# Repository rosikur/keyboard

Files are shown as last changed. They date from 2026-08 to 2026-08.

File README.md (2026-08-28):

# keyboard

I dont know what to call it so lets call it "keeb" because thats the name  of  the guide

This was my first keyboard , apart from my macropad ,the keyboard took 3 times , more on that on my Journal

## Features
- Us keyboard
- Del key with fn + Backspace
- 75 %
- Made with lots of hate and Caffeine
- Rotary Encoder
## How to assemble
First you go to jlcpcb and uplood the gerber files, i recommend black pcb colors
Then you go to Aliexpress and order all the parts from the BOM

In the meantime while it ships you start printing the Case,if your Printer is too small , half it or you can order it off print legion

Once everything is ready , you grab some solder and an iron , i recommend leaded solder makes it easier,firstly take your pi pico and add the  male pins,then put it trough and solder everything and snap off its legs outside

Then take your diodes,and turn the board around ,make sure the diodes are pointing  down in orientation and solder them,snap off its legs 

Then take your switchs,turn the board around and pit them all in and solder them one by one 

Last but not least ,add the rotary encoder and solder it

Also add the Stabalizers , watch a tiktok to put them togehter

put the ready board in the case add heated inserts and screw it together

add the key caps and youre done with assembly:D

## How to Software 
Set the Pi Pico to its Bootloader and connect it to your pc  take the uf2 zip and unzip , 

move the file to the pi labelled usb driver

thats it have fun! 

## Picture Gallary
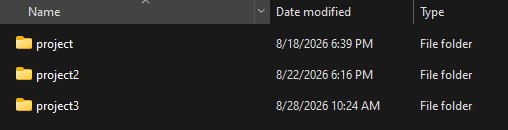
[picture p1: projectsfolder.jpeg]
3 Folders

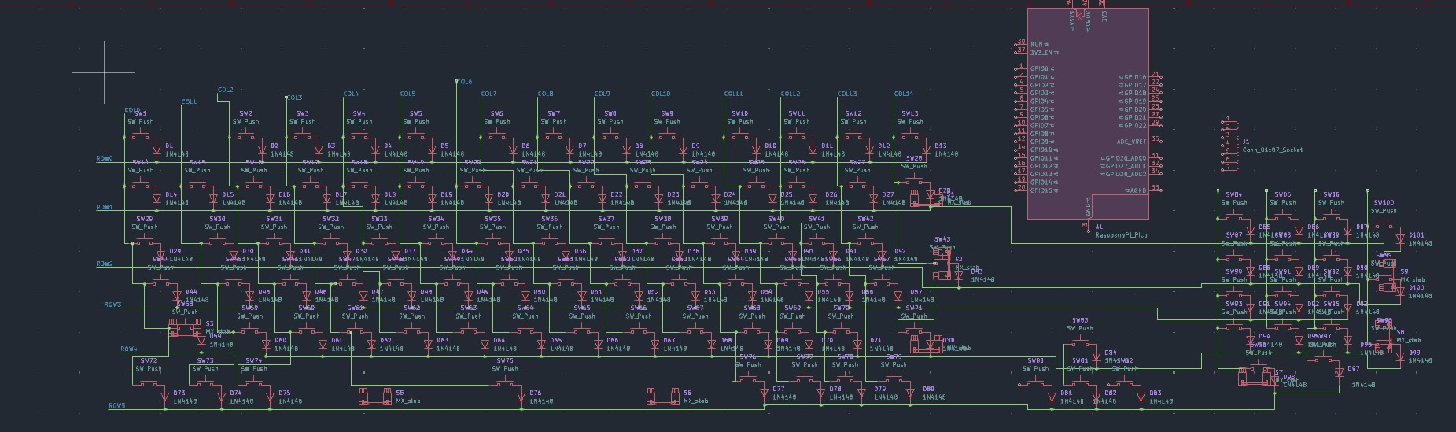
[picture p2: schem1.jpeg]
Schematic in the first folder

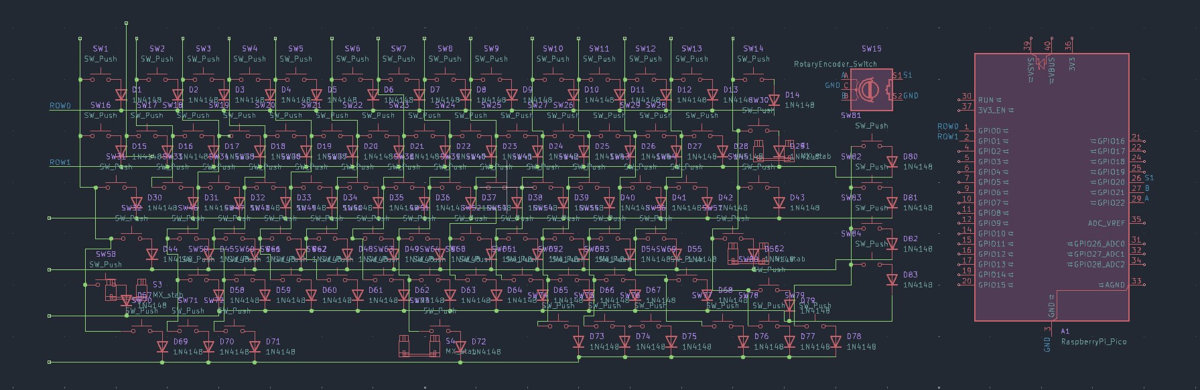
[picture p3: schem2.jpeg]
Schematic in the second folder

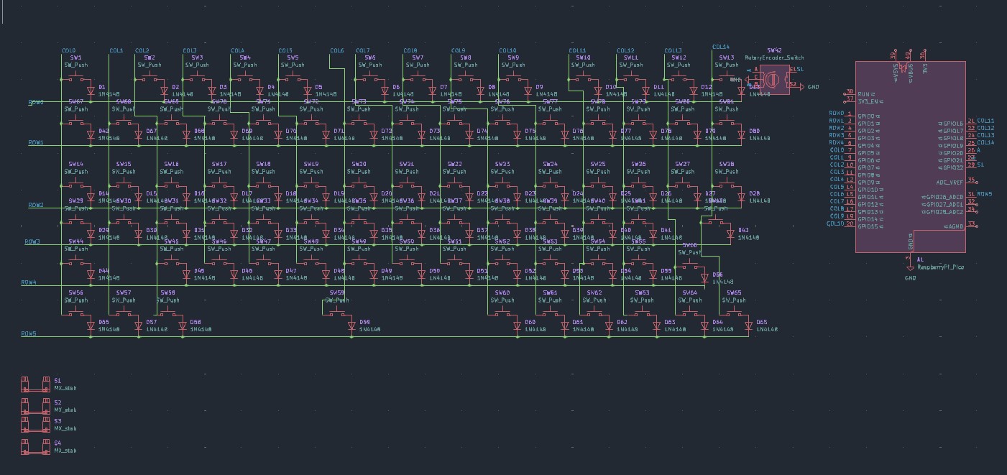
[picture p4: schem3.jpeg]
Schematic in the third folder

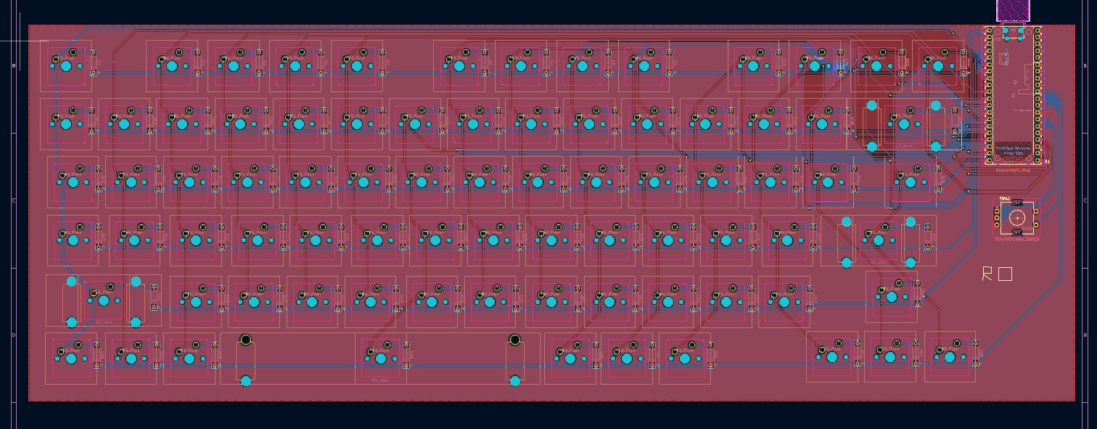
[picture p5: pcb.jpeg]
pcb

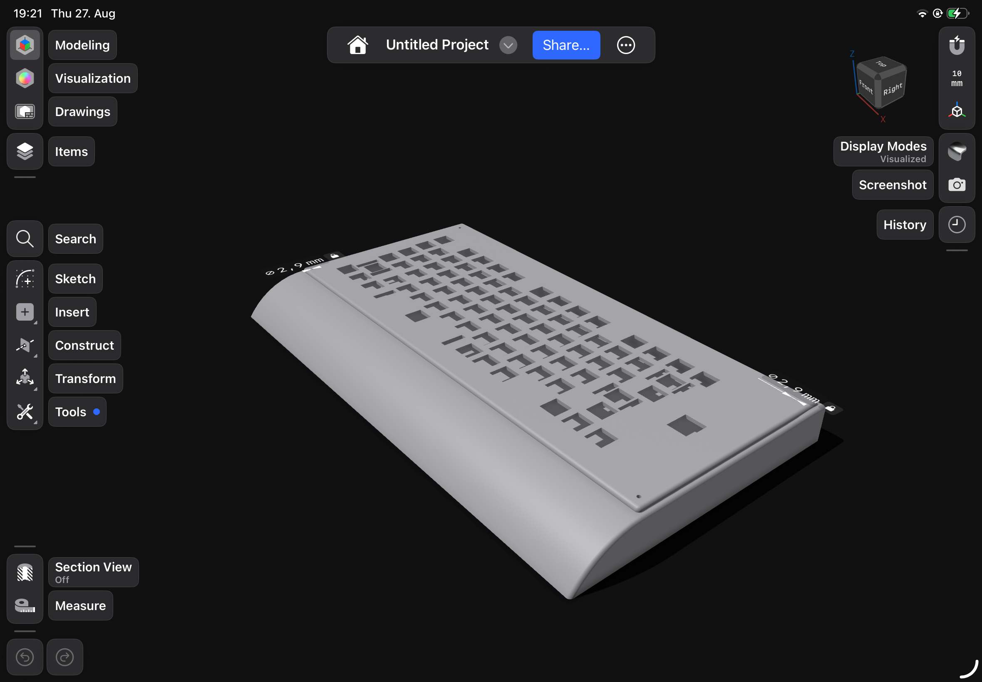
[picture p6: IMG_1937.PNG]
Cad software showing a keyboard


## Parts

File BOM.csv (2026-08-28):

Item | QNT | Price | Link | details
Switches | 162 | 13.39/45 * 4 = 53.56EUR = 62.48USD | https://a.aliexpress.com/_EJTCEpM | AKKO v3 pro cream blue
Keycaps | 2 Sets | 16.99EUR * 2 = 33.98EUR = 39.64USD | https://a.aliexpress.com/_Eyr32DU | cuul mc keycaps
Diodes | 160 | 1.39*2 + Duties = 5.78 | https://a.aliexpress.com/_EGyImLY
Rotary Encoder | 2 | 6.49+ Duties 3Eur = 9.49 Eur | https://a.aliexpress.com/_EjwhFqK
Orpheus Pico | 2 | 3.05 *2 + Duties = 9.10 | https://a.aliexpress.com/_ExrMmQe | in reality its a knockoff pi pico
PCB |  | 37.39
Cable |  | 6.49+ duties =9.49 | https://a.aliexpress.com/_EwkdJdC
MX Stab |  | 6.19+ Duties =9.19 | https://a.aliexpress.com/_EHf4OAA
 |  | welps that got out of hand
 |  | Total 167.98 EUR = 196.01

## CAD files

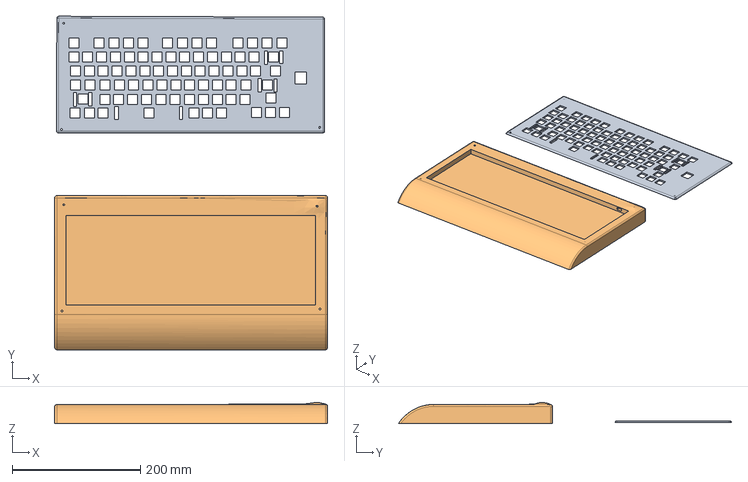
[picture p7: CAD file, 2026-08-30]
Case.step
425.0 x 519.3 x 33.4 mm

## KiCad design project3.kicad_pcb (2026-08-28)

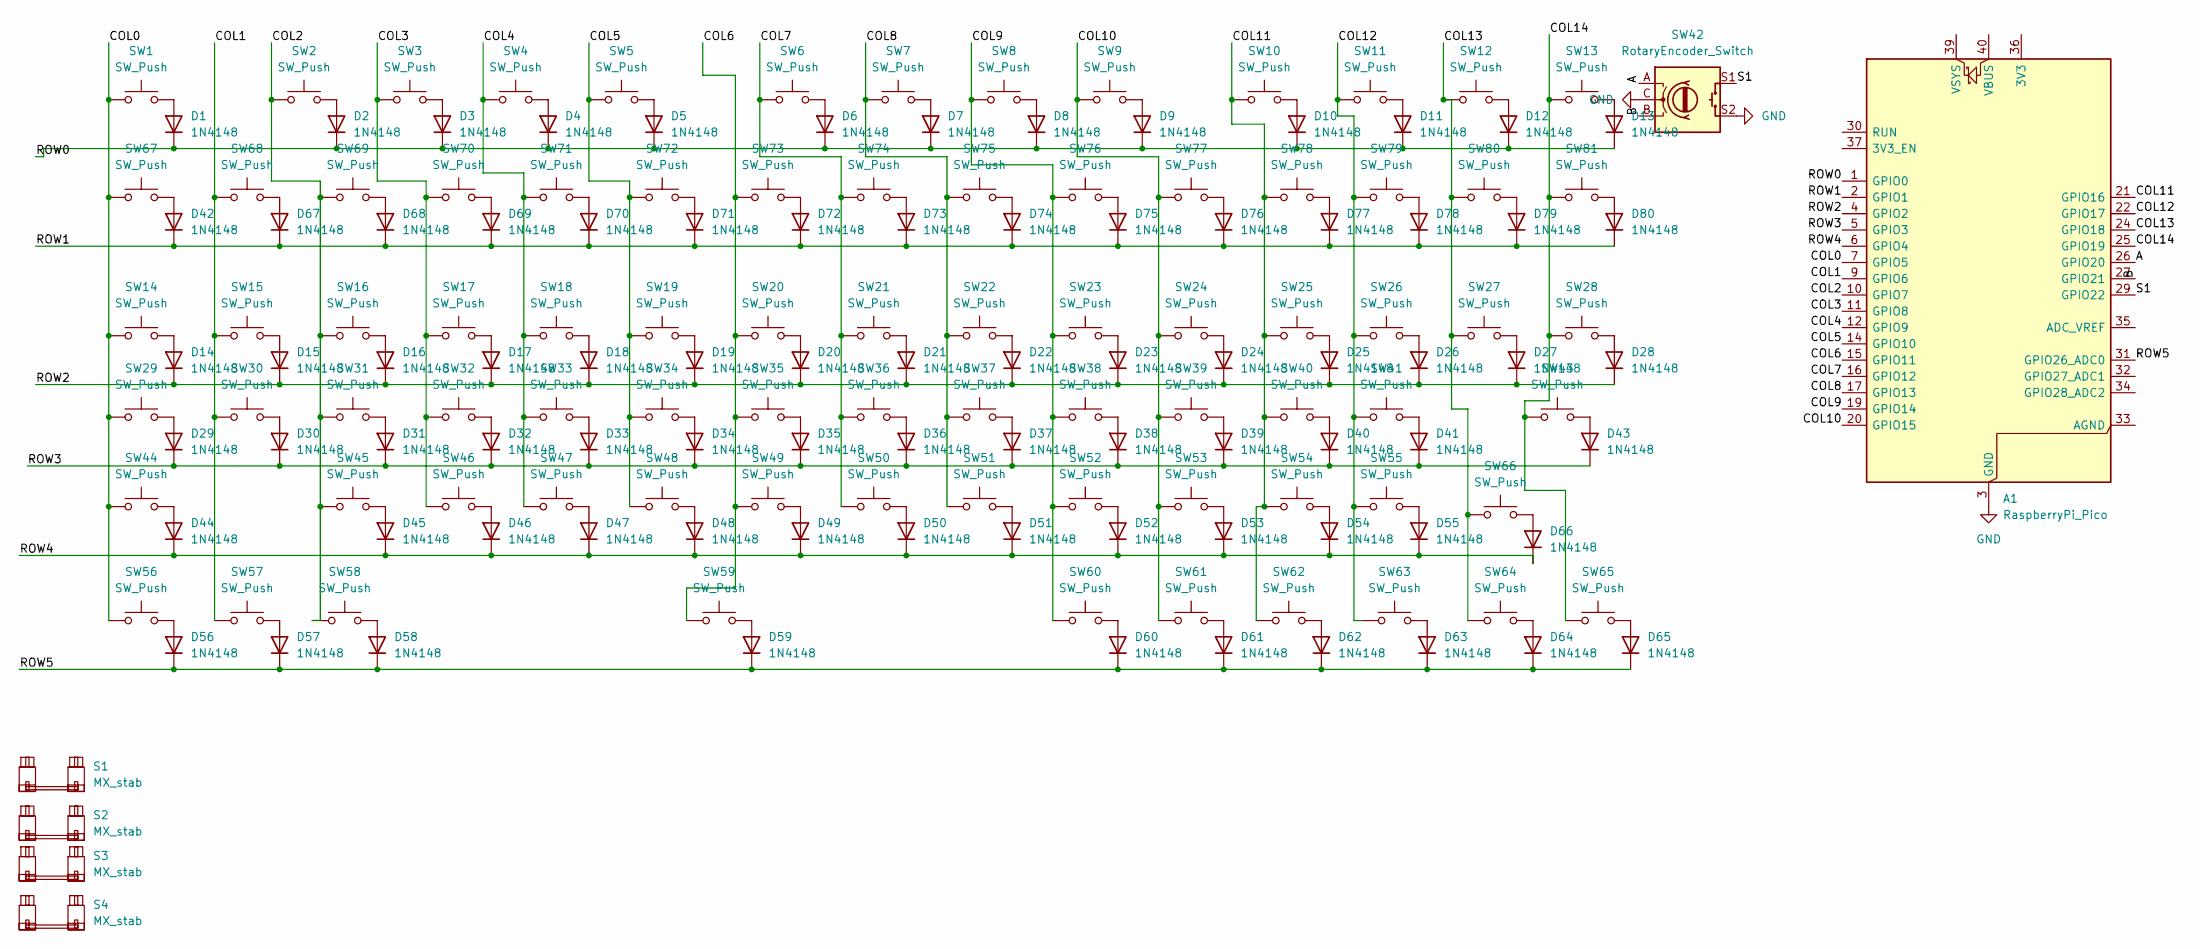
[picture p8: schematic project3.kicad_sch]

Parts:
A1: RaspberryPi_Pico; RaspberryPi_Pico_Common_Unspecified
D1, D2, D3, D4, D5, D6, D7, D8, D9, D10, D11, D12, D13, D14, D15, D16, D17, D18, D19, D20, D21, D22, D23, D24, D25, D26, D27, D28, D29, D30, D31, D32, D33, D34, D35, D36, D37, D38, D39, D40, D41, D42, D43, D44, D45, D46, D47, D48, D49, D50, D51, D52, D53, D54, D55, D56, D57, D58, D59, D60, D61, D62, D63, D64, D65, D66, D67, D68, D69, D70, D71, D72, D73, D74, D75, D76, D77, D78, D79, D80: 1N4148; D_DO-35_SOD27_P7.62mm_Horizontal
S1: MX_stab; STAB_MX_P_6.25u
S2, S3, S4: MX_stab; STAB_MX_2.25u
SW1, SW2, SW3, SW4, SW5, SW6, SW7, SW8, SW9, SW10, SW11, SW12, SW13, SW14, SW15, SW16, SW17, SW18, SW19, SW20, SW21, SW22, SW23, SW24, SW25, SW26, SW27, SW28, SW29, SW30, SW31, SW32, SW33, SW34, SW35, SW36, SW37, SW38, SW39, SW40, SW41, SW43, SW44, SW45, SW46, SW47, SW48, SW49, SW50, SW51, SW52, SW53, SW54, SW55, SW56, SW57, SW58, SW59, SW60, SW61, SW62, SW63, SW64, SW65, SW66, SW67, SW68, SW69, SW70, SW71, SW72, SW73, SW74, SW75, SW76, SW77, SW78, SW79, SW80, SW81: SW_Push; SW_MX_1u
SW42: RotaryEncoder_Switch; RotaryEncoder_Alps_EC11E-Switch_Vertical_H20mm

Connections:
/A: A1.26 (GPIO20), SW42.A
/B: A1.27 (GPIO21), SW42.B
/COL0: A1.7 (GPIO5), SW1.1, SW14.1, SW29.1, SW44.1, SW56.1, SW67.1
/COL1: A1.9 (GPIO6), SW15.1, SW30.1, SW57.1, SW68.1
/COL2: A1.10 (GPIO7), SW2.1, SW16.1, SW31.1, SW45.1, SW58.1, SW69.1
/COL4: A1.12 (GPIO9), SW4.1, SW18.1, SW33.1, SW47.1, SW71.1
/COL5: A1.14 (GPIO10), SW5.1, SW19.1, SW34.1, SW48.1, SW72.1
/COL6: A1.15 (GPIO11), SW20.1, SW35.1, SW49.1, SW59.1, SW73.1
/COL7: A1.16 (GPIO12), SW6.1, SW21.1, SW36.1, SW50.1, SW74.1
/COL8: A1.17 (GPIO13), SW7.1, SW22.1, SW37.1, SW51.1, SW75.1
/COL9: A1.19 (GPIO14), SW8.1, SW23.1, SW38.1, SW52.1, SW60.1, SW76.1
/COL10: A1.20 (GPIO15), SW9.1, SW24.1, SW39.1, SW53.1, SW61.1, SW77.1
/COL11: A1.21 (GPIO16), SW10.1, SW25.1, SW40.1, SW54.1, SW62.1, SW78.1
/COL12: A1.22 (GPIO17), SW11.1, SW26.1, SW41.1, SW55.1, SW63.1, SW79.1
/COL13: A1.24 (GPIO18), SW12.1, SW27.1, SW64.1, SW66.1, SW80.1
/COL14: A1.25 (GPIO19), SW13.1, SW28.1, SW43.1, SW65.1, SW81.1
/ROW0: A1.1 (GPIO0), D1.1 (K), D2.1 (K), D3.1 (K), D4.1 (K), D5.1 (K), D6.1 (K), D7.1 (K), D8.1 (K), D9.1 (K), D10.1 (K), D11.1 (K), D12.1 (K), D13.1 (K)
/ROW1: A1.2 (GPIO1), D42.1 (K), D67.1 (K), D68.1 (K), D69.1 (K), D70.1 (K), D71.1 (K), D72.1 (K), D73.1 (K), D74.1 (K), D75.1 (K), D76.1 (K), D77.1 (K), D78.1 (K), D79.1 (K), D80.1 (K)
/ROW2: A1.4 (GPIO2), D14.1 (K), D15.1 (K), D16.1 (K), D17.1 (K), D18.1 (K), D19.1 (K), D20.1 (K), D21.1 (K), D22.1 (K), D23.1 (K), D24.1 (K), D25.1 (K), D26.1 (K), D27.1 (K), D28.1 (K)
/ROW3: A1.5 (GPIO3), D29.1 (K), D30.1 (K), D31.1 (K), D32.1 (K), D33.1 (K), D34.1 (K), D35.1 (K), D36.1 (K), D37.1 (K), D38.1 (K), D39.1 (K), D40.1 (K), D41.1 (K), D43.1 (K)
/ROW4: A1.6 (GPIO4), D44.1 (K), D45.1 (K), D46.1 (K), D47.1 (K), D48.1 (K), D49.1 (K), D50.1 (K), D51.1 (K), D52.1 (K), D53.1 (K), D54.1 (K), D55.1 (K), D66.1 (K)
/ROW5: A1.31 (GPIO26_ADC0), D56.1 (K), D57.1 (K), D58.1 (K), D59.1 (K), D60.1 (K), D61.1 (K), D62.1 (K), D63.1 (K), D64.1 (K), D65.1 (K)
/S1: A1.29 (GPIO22), SW42.S1
GND: A1.3 (GND), A1.8 (GND), A1.13 (GND), A1.18 (GND), A1.23 (GND), A1.28 (GND), A1.38 (GND), SW42.C, SW42.S2
unnamed: D1.2 (A), SW1.2
unnamed: D2.2 (A), SW2.2
unnamed: D3.2 (A), SW3.2
unnamed: D4.2 (A), SW4.2
unnamed: D5.2 (A), SW5.2
unnamed: D6.2 (A), SW6.2
unnamed: D7.2 (A), SW7.2
unnamed: D8.2 (A), SW8.2
unnamed: D9.2 (A), SW9.2
unnamed: D10.2 (A), SW10.2
unnamed: D11.2 (A), SW11.2
unnamed: D12.2 (A), SW12.2
unnamed: D13.2 (A), SW13.2
unnamed: D14.2 (A), SW14.2
unnamed: D15.2 (A), SW15.2
unnamed: D16.2 (A), SW16.2
unnamed: D17.2 (A), SW17.2
unnamed: D18.2 (A), SW18.2
unnamed: D19.2 (A), SW19.2
unnamed: D20.2 (A), SW20.2
unnamed: D21.2 (A), SW21.2
unnamed: D22.2 (A), SW22.2
unnamed: D23.2 (A), SW23.2
unnamed: D24.2 (A), SW24.2
unnamed: D25.2 (A), SW25.2
unnamed: D26.2 (A), SW26.2
unnamed: D27.2 (A), SW27.2
unnamed: D28.2 (A), SW28.2
unnamed: D29.2 (A), SW29.2
unnamed: D30.2 (A), SW30.2
unnamed: D31.2 (A), SW31.2
unnamed: D32.2 (A), SW32.2
unnamed: D33.2 (A), SW33.2
unnamed: D34.2 (A), SW34.2
unnamed: D35.2 (A), SW35.2
unnamed: D36.2 (A), SW36.2
unnamed: D37.2 (A), SW37.2
unnamed: D38.2 (A), SW38.2
unnamed: D39.2 (A), SW39.2
unnamed: D40.2 (A), SW40.2
unnamed: D41.2 (A), SW41.2
unnamed: D42.2 (A), SW67.2
unnamed: D43.2 (A), SW43.2
unnamed: D44.2 (A), SW44.2
unnamed: D45.2 (A), SW45.2
unnamed: D46.2 (A), SW46.2
unnamed: D47.2 (A), SW47.2
unnamed: D48.2 (A), SW48.2
unnamed: D49.2 (A), SW49.2
unnamed: D50.2 (A), SW50.2
unnamed: D51.2 (A), SW51.2
unnamed: D52.2 (A), SW52.2
unnamed: D53.2 (A), SW53.2
unnamed: D54.2 (A), SW54.2
unnamed: D55.2 (A), SW55.2
unnamed: D56.2 (A), SW56.2
unnamed: D57.2 (A), SW57.2
unnamed: D58.2 (A), SW58.2
unnamed: D59.2 (A), SW59.2
unnamed: D60.2 (A), SW60.2
unnamed: D61.2 (A), SW61.2
unnamed: D62.2 (A), SW62.2
unnamed: D63.2 (A), SW63.2
unnamed: D64.2 (A), SW64.2
unnamed: D65.2 (A), SW65.2
unnamed: D66.2 (A), SW66.2
unnamed: D67.2 (A), SW68.2
unnamed: D68.2 (A), SW69.2
unnamed: D70.2 (A), SW71.2
unnamed: D71.2 (A), SW72.2
unnamed: D72.2 (A), SW73.2
unnamed: D73.2 (A), SW74.2
unnamed: D74.2 (A), SW75.2
unnamed: D75.2 (A), SW76.2
unnamed: D76.2 (A), SW77.2
unnamed: D77.2 (A), SW78.2
unnamed: D78.2 (A), SW79.2
unnamed: D79.2 (A), SW80.2
unnamed: D80.2 (A), SW81.2

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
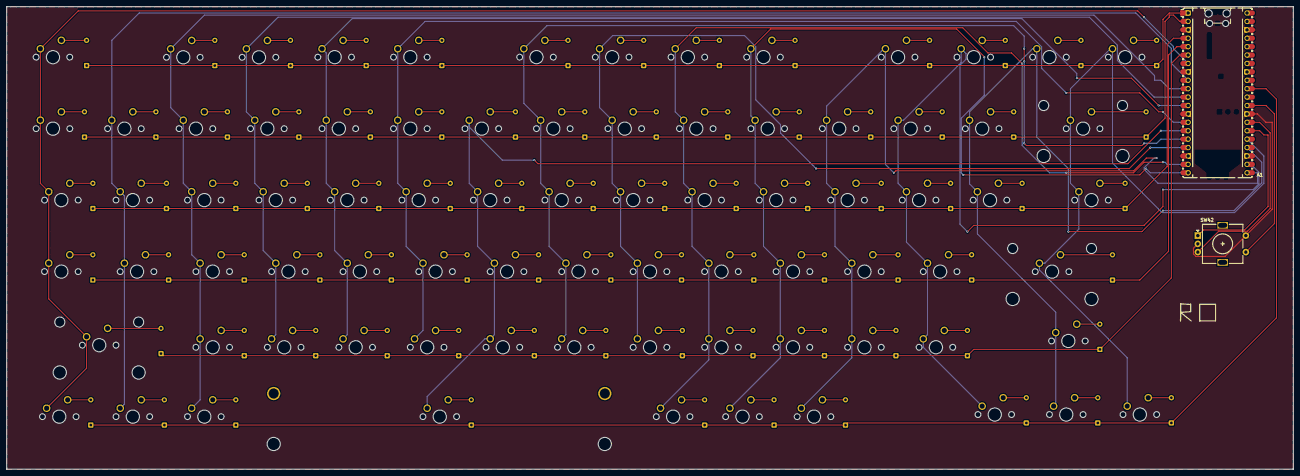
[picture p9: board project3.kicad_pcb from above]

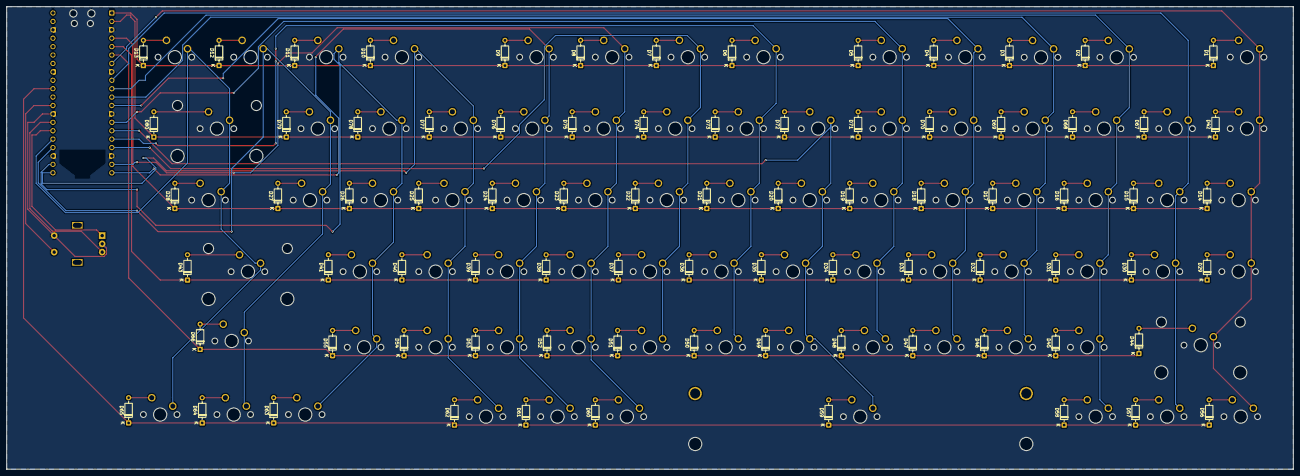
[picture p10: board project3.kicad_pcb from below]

Board: 2 copper layers, 388.6 x 139.7 mm, 166 parts (80 on the bottom side), 105 nets.

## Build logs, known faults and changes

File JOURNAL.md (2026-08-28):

STEP 1 
Schemmatic
So this is how it starts ....

This damn Schematic .....  

IT TOOK 3 TRIES

THREE

With the schematic Alone we're at about 10 hours as it took 3 times proof:

3 Folders

What went wrong the first time you ask?  Well:

I wanted to do a 110 % Keyboard with a tft Display , a rotary encoder  etc etc  but  we were using a Raspberry Pi Pico so obviously not enough GPIO pins (Youre always Smarter afterwards)

Schematic in the first folder

Okay what now? Obviously a 75 % Keyboard without that fancy tft but still a Rotary Encoder for Volume or smth( Software hasnt been made yet)

Schematic in the second folder

It still didnt work, the Matrix gave me headaches annd i could'nt figure out why everything was connected to the right so ofcourse I gave up(for my  Sanity)

But whats worse than giving up? Of course not trying again so I started again .....

And I Swear to God everything went wrong...
I wired everything incorrectly , I FORGOT THE NUMBER ROW and  kept putting it off (my friends keep telling me i have adhd.... I doubt it but im not sure)

But with one Monster Strawberry dreams I worked until 2 am and finished it evantually :P

We finished with  a 75% Keyboard without those stupid Keys like Ins Hime Pgup del(only useful) with a Volume Knob and a cool Pi Pico It also has F Keys as im not a masochist  

Here is the finished Schematic:

Schematic in the third folder

All in All 10- 11 Hours (I tracked some but not all on Lapse)

Part  2 The Cool Part aka the pcb

It  was a blur really as i did this at 2am but it was pretty easy with a ruler (jk)

SO i figured out something amazing 

if you put the  schematic viewer and the pcb viewer next to eachother in the splitscreen or sepperate  Monitors , you are able to press any item on the  schematic or vice versa in the pcb  you select the item on both panels which is soooo great mmakes everything wayyyy easier

I selected a grid and sticked to it ... SIKE i did everything with the german "Augenmass" and it worked  fine until i realized i forgot to flip the diodes yeah rookie mistake but thats mee a rookie 

Oh right i forgot to mention assigning the footprints if you press on something then go down to the last of  the same item and press ctrl or shift you select everything between them  

Oh i got distracted...

Routing the  traces was a bit annoying as there were only two layers but i got trough it with a lot of vias

Heres the finished Part
pcb

btw took like  6-8 hours ( till 2am of course)
part  3 the bill of materials
see bom.csv 
DAYUM this is fucking expensive
so why did i pick those : I scrolled on AliExpress ( thats it)

oh for the switches i just scrolled  on tiktoks  

and i love the keycaps because i love Minecraft
this took like 3 whole damn hours D:

Stand 25th of August 

TODO : 3d case firmware (oh no)  read me  adding pictures ... I feel like ill stay upto 2 am

THE NEXT DAY (and night)

Lets start with the case shall we?
I made an absolutely beatiful case look at it:

Cad software showing a keyboard 

As you can see its not opencad or whatever the guide told me,its shapr3d because my POS laptop cant handle anything that needs more than a gig of ram
designing it was pretty fun,i watched some youtube while doing it.

in total 4h 

But now onto the firmware ...

I hate it I hate itI hate itI hate itI hate itI hate itI hate itI hate itI hate itI hate itI hate itI hate itI hate itI hate itI hate itI hate itI hate itI hate itI hate itI hate itI hate itI hate itI hate itI hate itI hate itI hate itI hate itI hate itI hate it

Its now 2 am its finnaly working 

Mostly were errors like syntax,pins col mismatch not working letters(tried making the euro and üöä) which didnt work ,my head hurts , once i am done i will goto sleep i only have to finish writing ts zzzzzz zzzz zzzz 

Anyways this took like6 - 7 hours but for the mental tourment i would give myself 10000 h
anyways good night zzzzz zzzz

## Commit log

2026-08-25 Add journal entry for keyboard project progress
    Documented the process of creating a custom keyboard, including schematic design, PCB layout, and bill of materials.
2026-08-28 Update JOURNAL.md with design and firmware notes
    Document progress on case design and firmware issues encountered during development.
2026-08-28 Update README with assembly and software instructions
    Added detailed assembly instructions and software setup for the keyboard project.
2026-08-28 Fix typos and enhance clarity in README.md
    Corrected typos and improved formatting in assembly instructions. Added additional spacing for clarity in software setup section.
2026-10-29 Document keyboard project progress in JOURNAL.md
    Added detailed journal entries documenting the keyboard project, including schematics, PCB design, and case creation with time spent on each phase.
2026-10-29 Add assembled CAD image to README
2026-10-29 Fix bill of materials table
2026-10-29 moved bom into the root
